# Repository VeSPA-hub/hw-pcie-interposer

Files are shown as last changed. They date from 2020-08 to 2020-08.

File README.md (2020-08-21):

# PCIe interposer

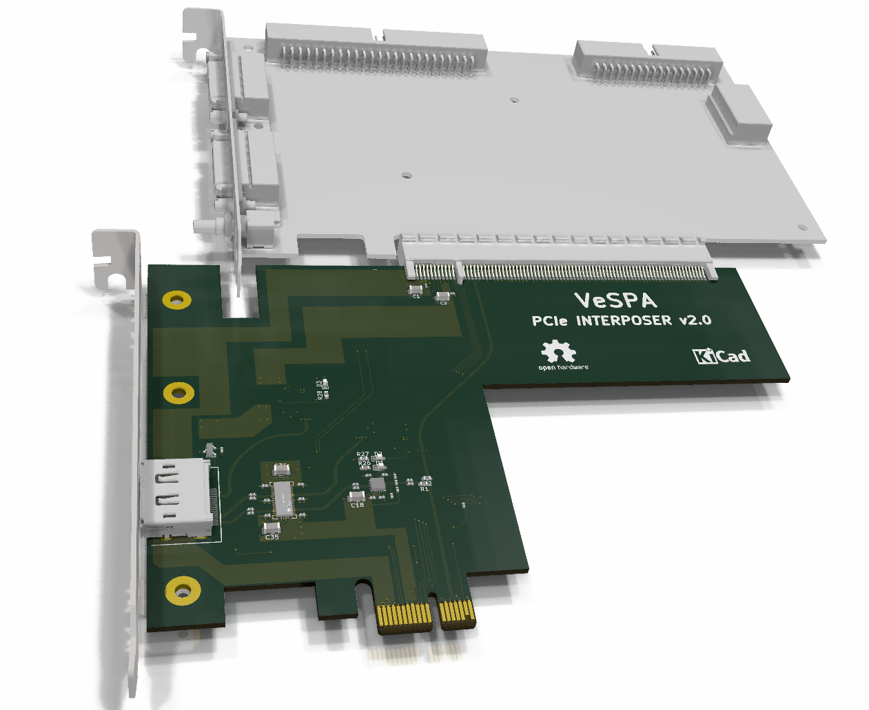
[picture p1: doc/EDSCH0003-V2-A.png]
interposer


Board design files of the VeSPA PCIe interposer

	Note: This design was performed in KiCad nightly , you will need a Nightly build to open and edit these source files.

# Status

This version has not been fully tested yet.

# What it is

This board can tap PCIe signals (RX, TX and clock) at Gen2 speed.
Signals go to a redriver before they are sent to the actual analyzer using a DisplayPort cable.

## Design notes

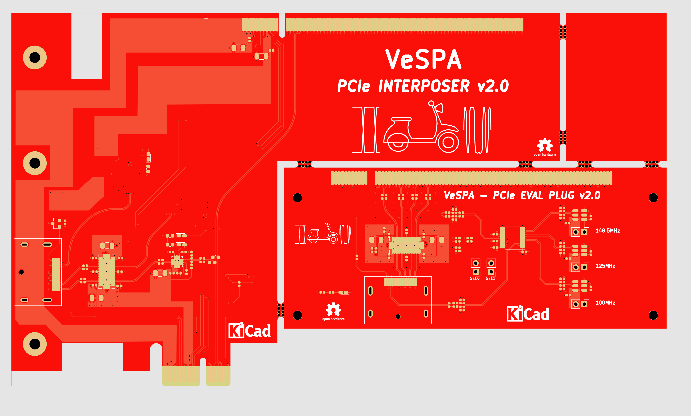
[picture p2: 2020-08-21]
gerber/board.png

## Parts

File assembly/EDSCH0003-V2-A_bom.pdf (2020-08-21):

EDSCH0003-V2-A

Page 1

Item | Qty | Reference | NC | Value | Footprint | Manufacturer | Part number | Mouser ordering code
1 | 7 | C1,C2,C18,C19,C20,C35,C36 | | 10uF | 1206 | TAIYO YUDEN | TMK316BJ106KL-T | 963-TMK316BJ106KL-T
2 | 6 | C6,C7,C8,C9,C10,C11 | | 10nF | 0402 | WURTH ELEKTRONIK | 885012205031 | 710-885012205031
3 | 23 | C3,C4,C5,C12,C13,C14,C15,C16,C17,C21,C22,C23,C24,C25,C26, C27,C28,C29,C30,C31,C32,C33,C34 | | 100nF | 0402 | WURTH ELEKTRONIK | 885012105016 | 710-885012105016
4 | 3 | D1,D2,D3 | | LED | 0603 | WURTH ELEKTRONIK | 150060VS55040 | 710-150060VS55040
5 | 3 | FB1,FB2,FB3 | | 600R | 0402 | TDK | MMZ1005S601HT000 | 810-MMZ1005S601HT000
6 | 1 | J1 | | PCIE EDGE x16 | | AMPHENOL FCI | 10146027-A40010LF | 649-10146027A40010LF
7 | 1 | J2 | | DISPLAYPORT | | MOLEX | 47272-0001 | 538-47272-0001
8 | 9 | R1,R2,R3,R4,R5,R6,R26,R27,R28 | | 680R | 0603 | VISHAY / DALE | CRCW0603680RJNEAC | 71-CRCW0603680RJNEAC
9 | 18 | R7,R8,R9,R10,R11,R12,R13,R14,R15,R20,R30,R31,R32,R33,R34 ,R35,R36,R37 | NC
10 | 4 | R16,R17,R18,R29 | | 33K | 0402 | VISHAY / DALE | CRCW040233K0FKEDC | 71-CRCW040233K0FKEDC
11 | 3 | R19,R21,R22 | | 0R | 0402 | VISHAY / DALE | CRCW04020000Z0EDC | 71-CRCW04020000Z0EDC
12 | 3 | R23,R24,R25 | | 100K | 0402 | VISHAY / DALE | CRCW0402100KFKEDC | 71-CRCW0402100KFKEDC
13 | 1 | U1 | | 11LC160T | SOT23 | MICROCHIP TECHNOLOGY | 11LC160T-I/TT | 579-11LC160T-I/TT
14 | 3 | U2,U3,U4 | | ONET1191P | QFN16 | TEXAS INSTRUMENTS | ONET1191PRGTT | 595-ONET1191PRGTT
15 | 1 | U5 | | SN65LVPE504 | PWQFN42 | TEXAS INSTRUMENTS | SN65LVPE504RUAR | 595-SN65LVPE504RUAR

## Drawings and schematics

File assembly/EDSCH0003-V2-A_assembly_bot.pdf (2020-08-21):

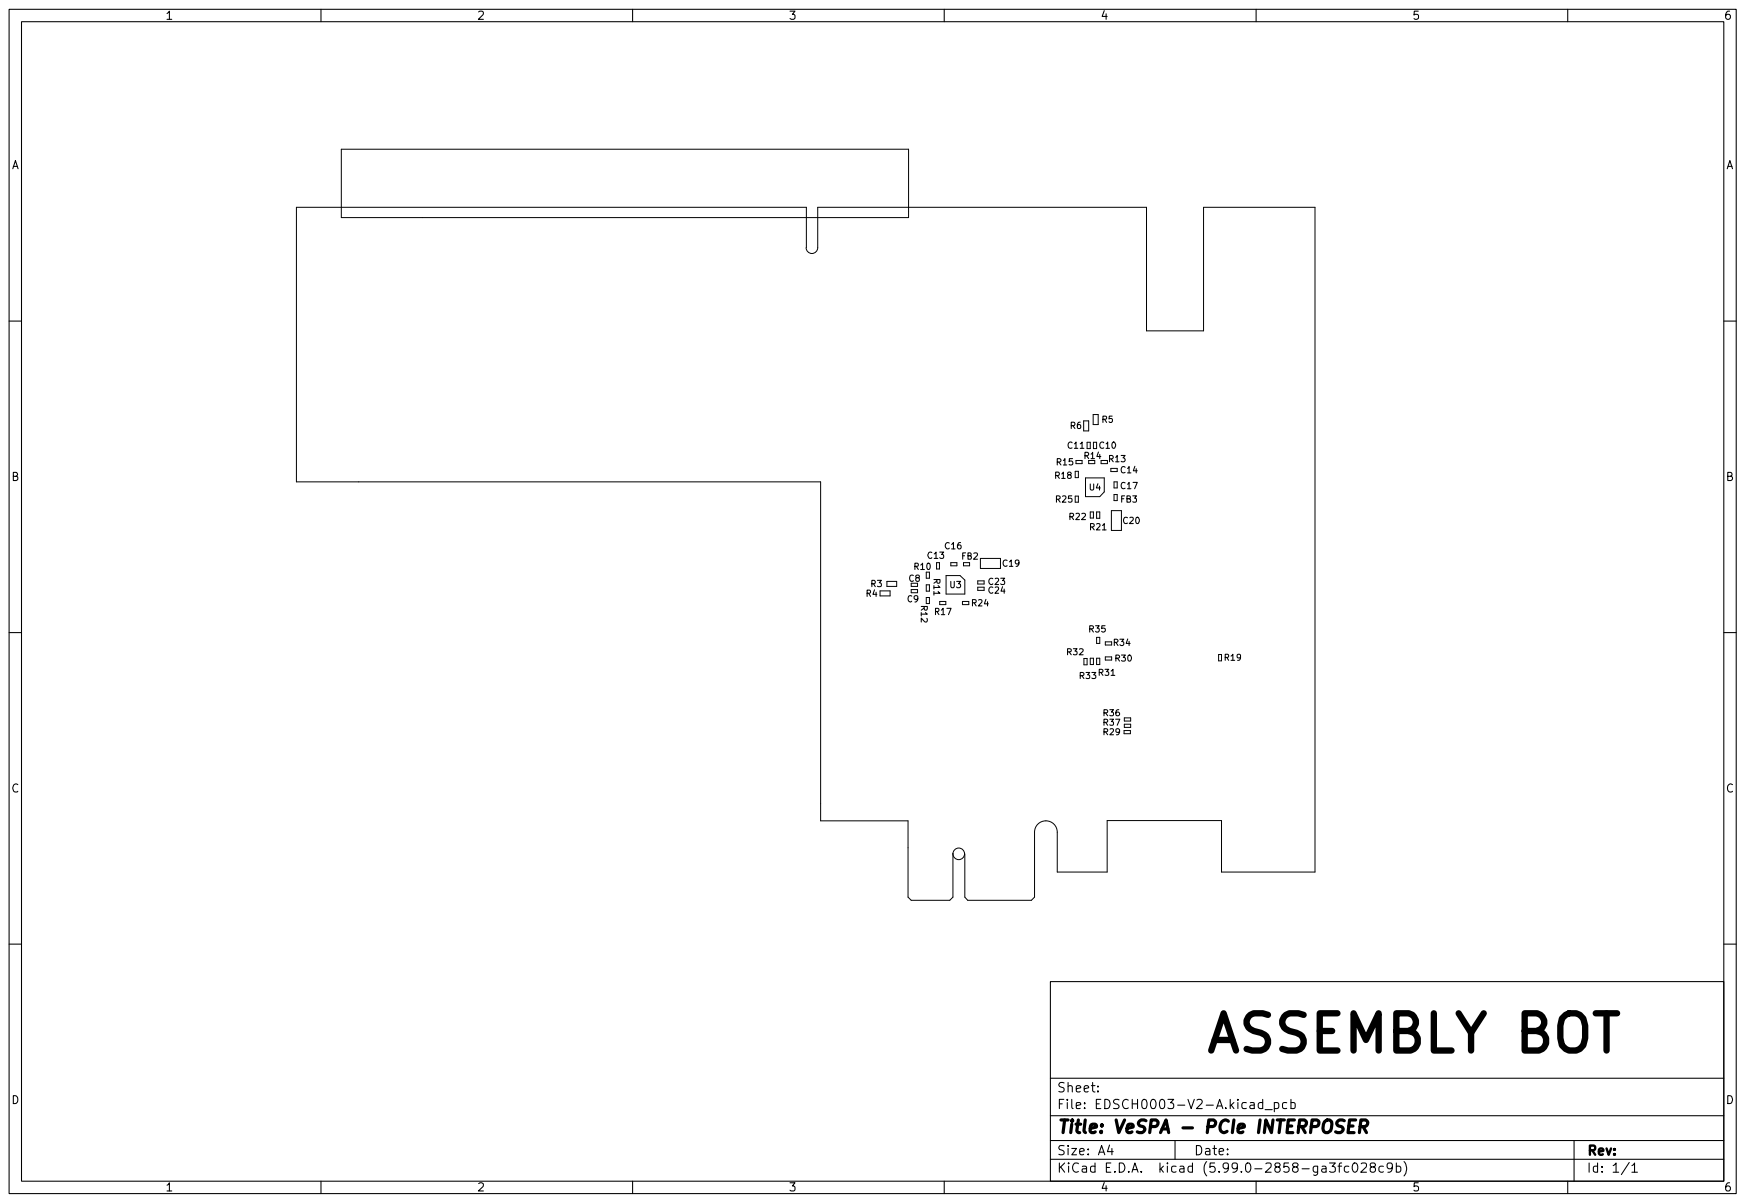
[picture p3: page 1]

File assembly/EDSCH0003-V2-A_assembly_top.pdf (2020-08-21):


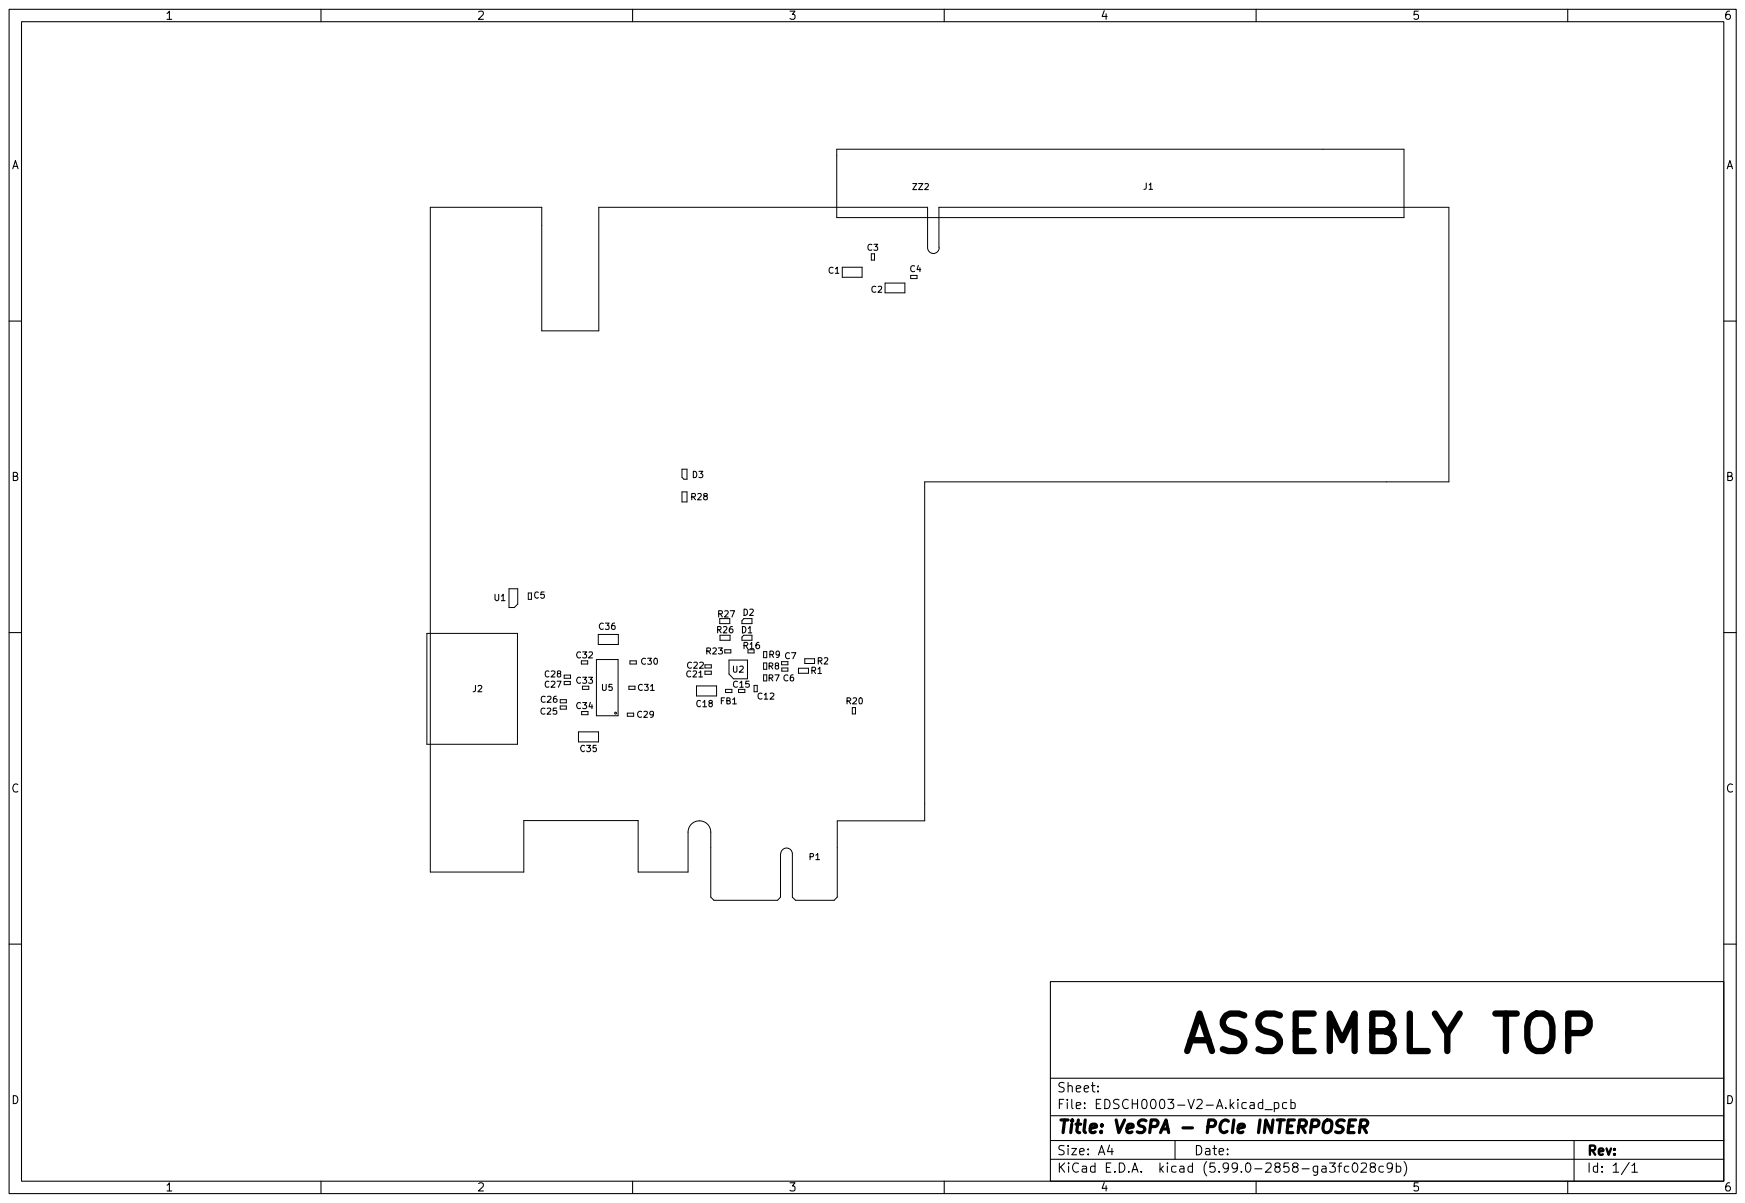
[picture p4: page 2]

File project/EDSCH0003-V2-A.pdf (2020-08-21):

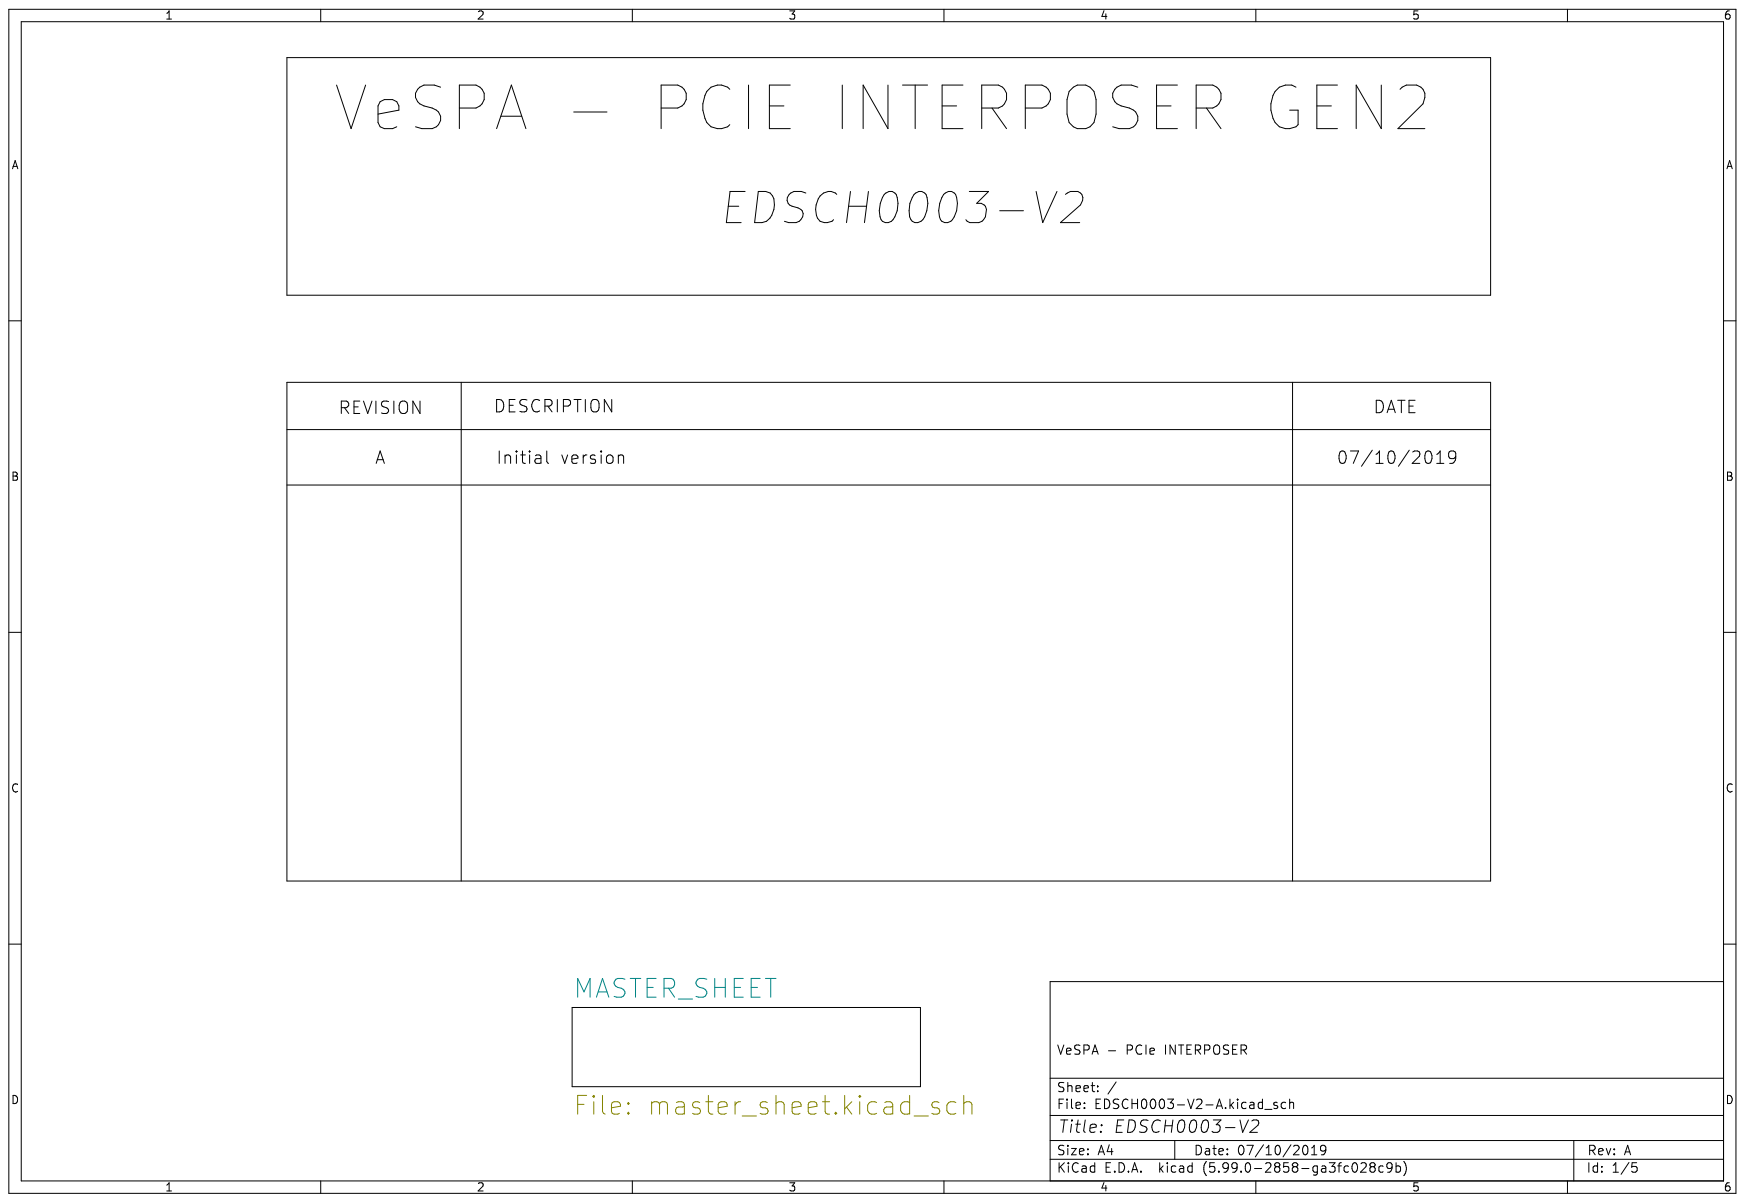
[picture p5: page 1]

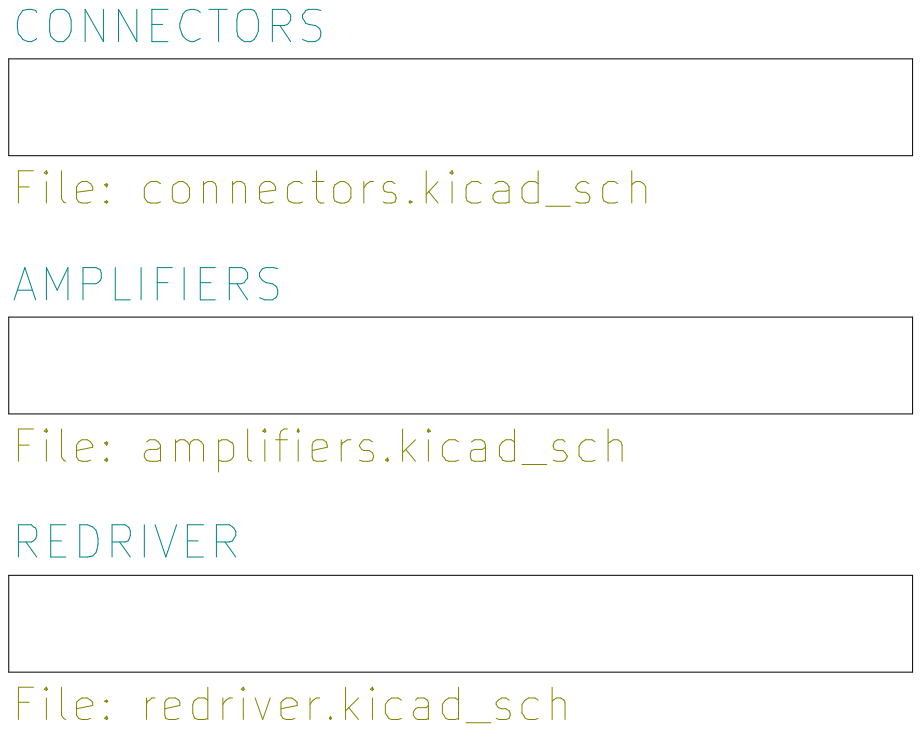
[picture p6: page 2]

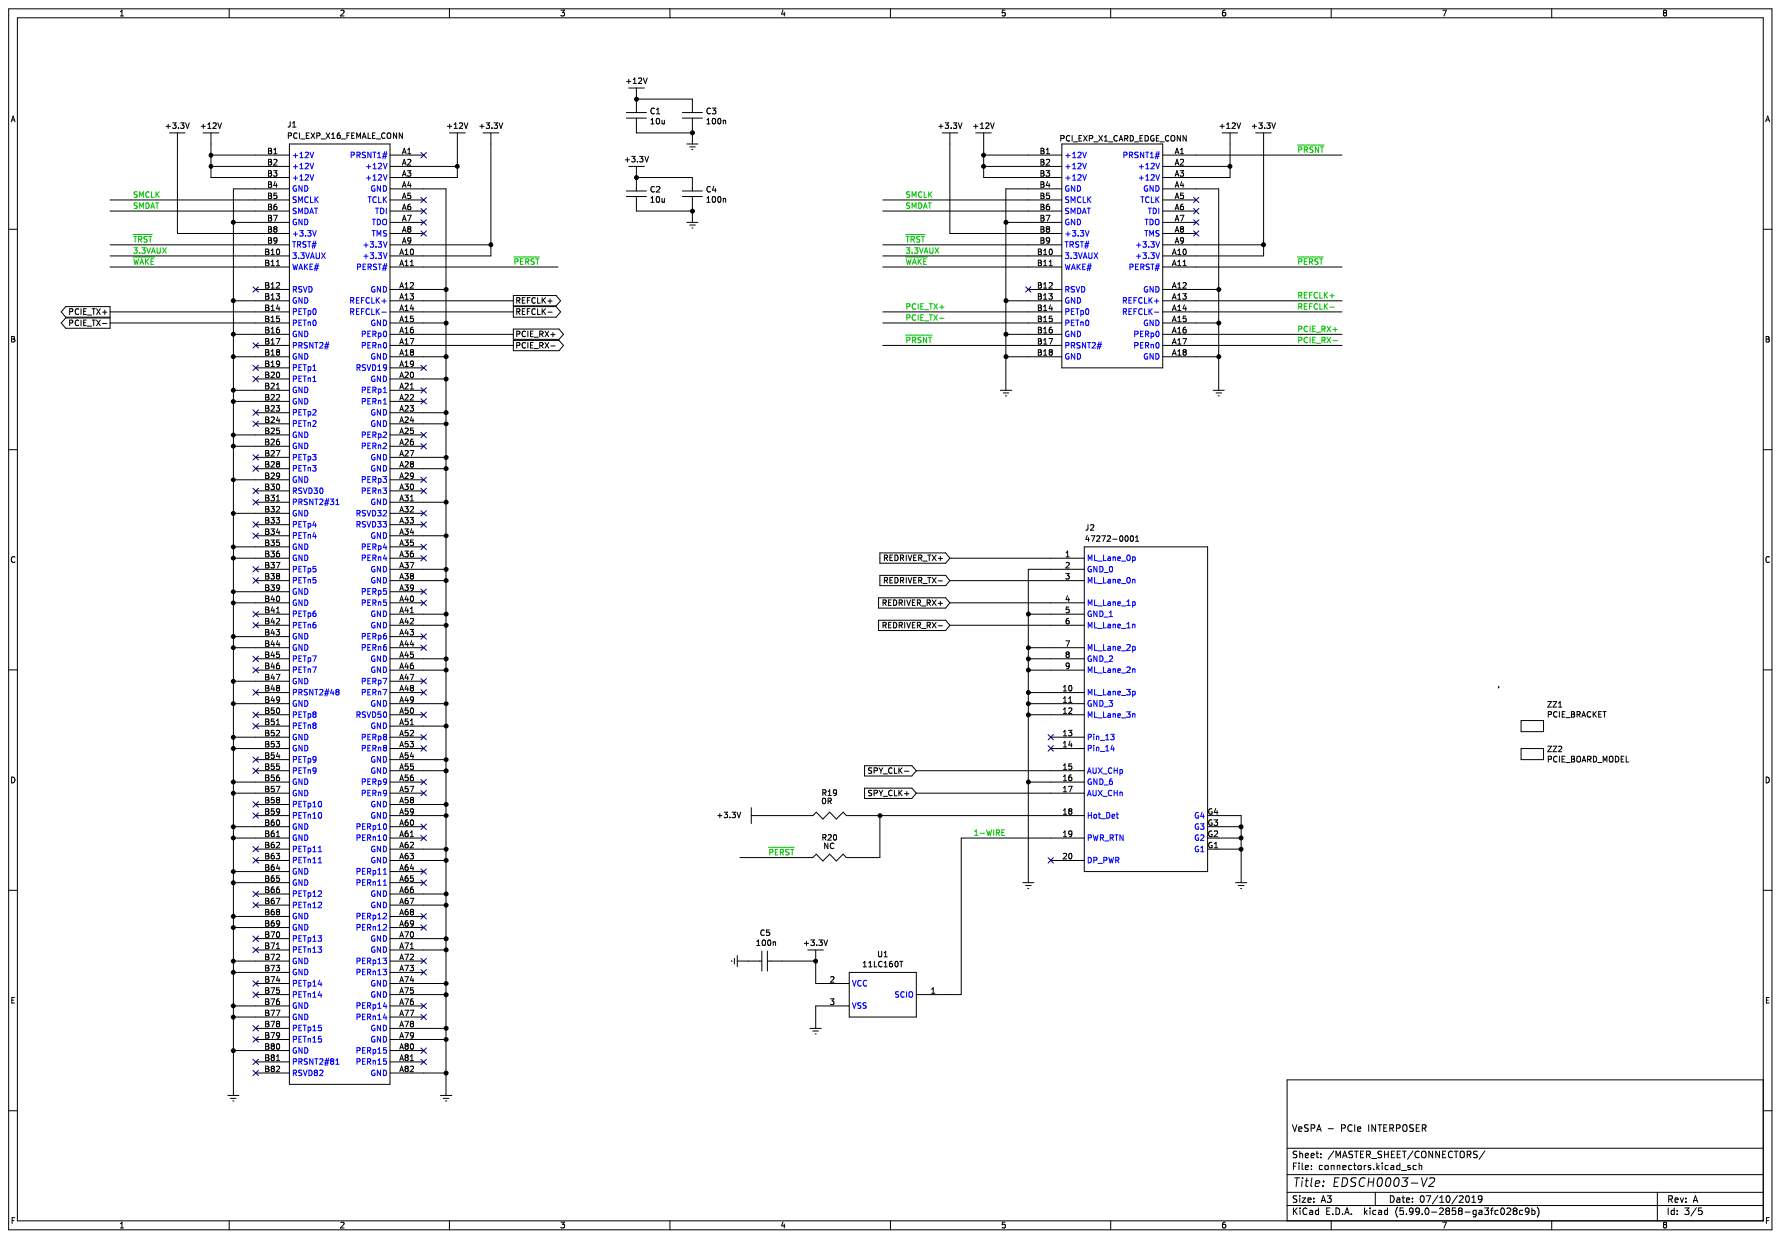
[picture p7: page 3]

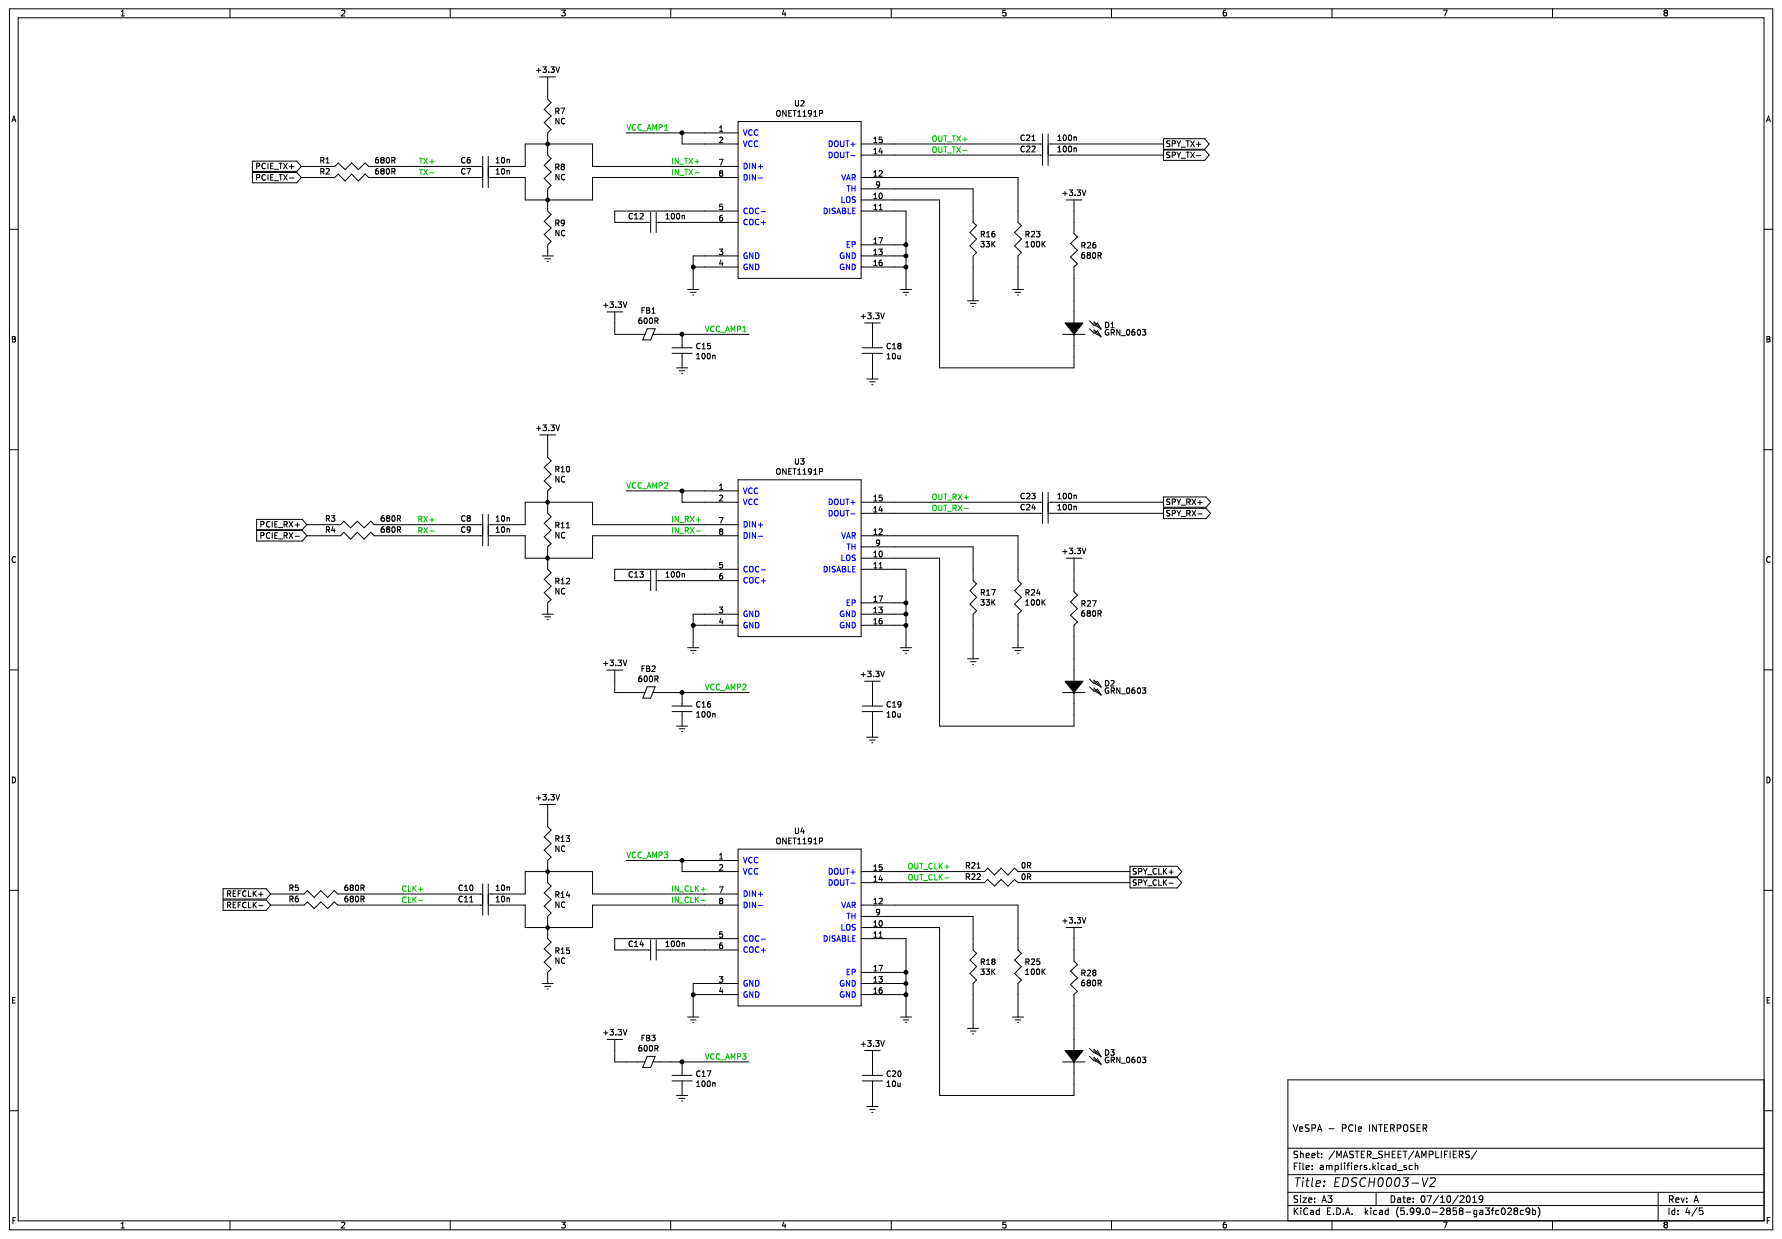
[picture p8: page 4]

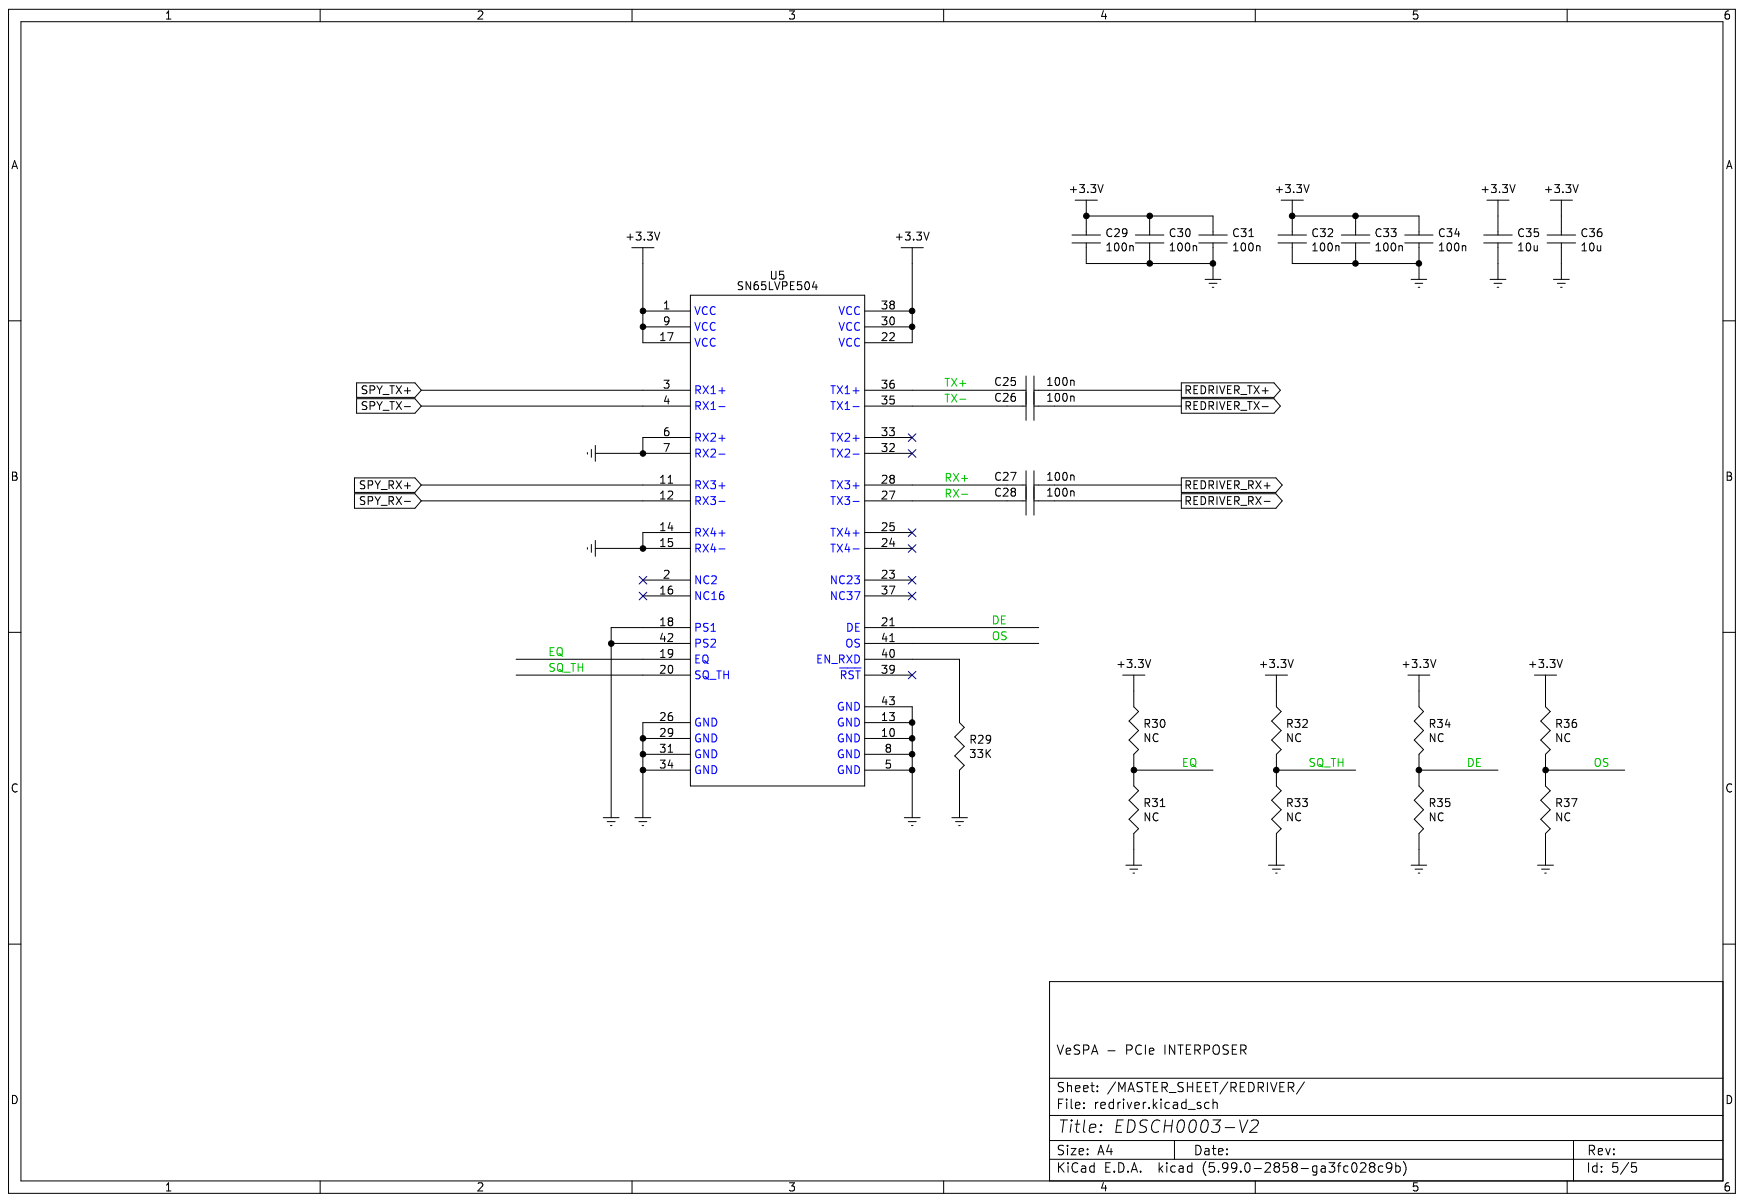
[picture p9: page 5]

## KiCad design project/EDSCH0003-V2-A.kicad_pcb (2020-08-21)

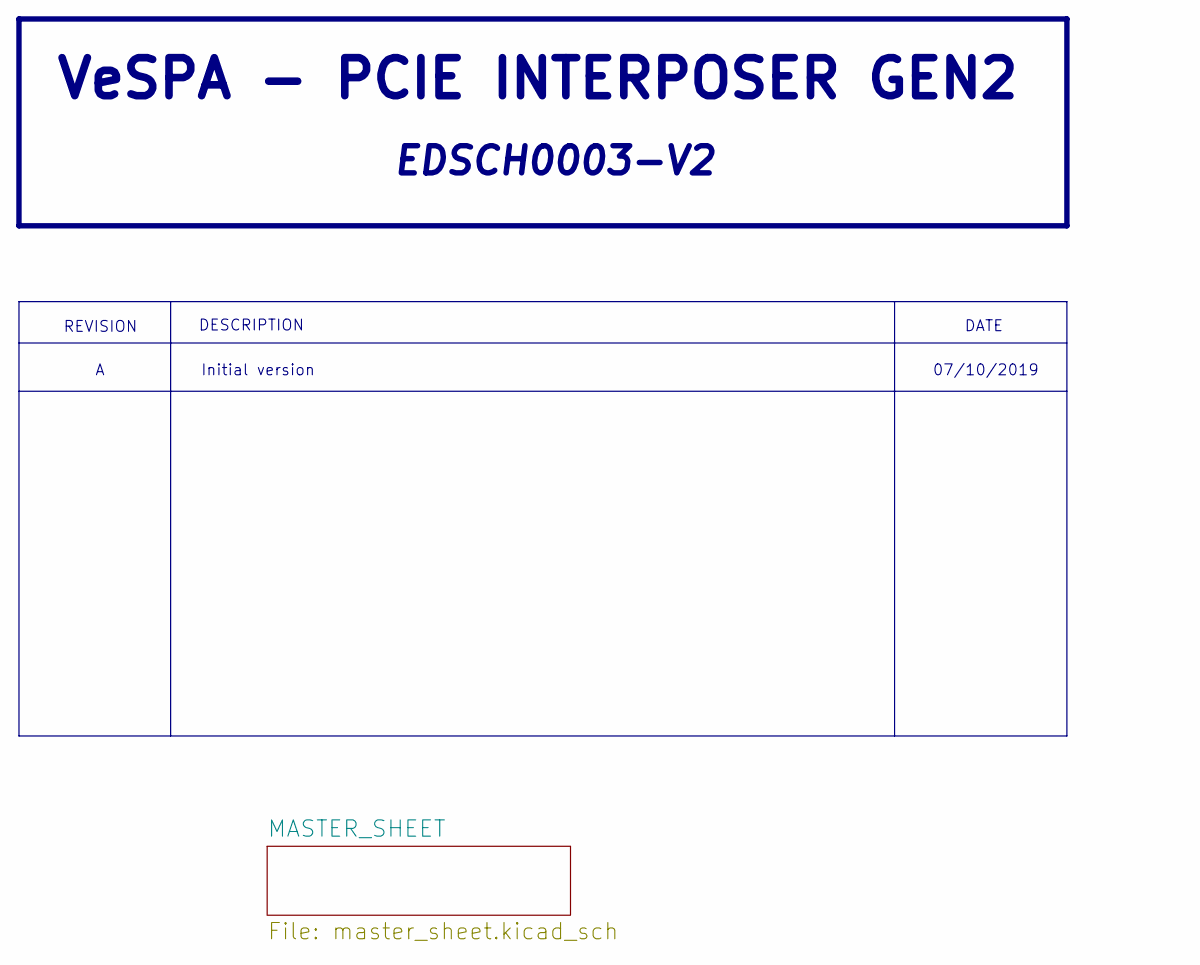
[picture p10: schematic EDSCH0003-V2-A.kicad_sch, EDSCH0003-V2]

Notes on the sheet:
VeSPA - PCIE INTERPOSER GEN2
REVISION
DESCRIPTION
Initial version
EDSCH0003-V2
DATE
07/10/2019

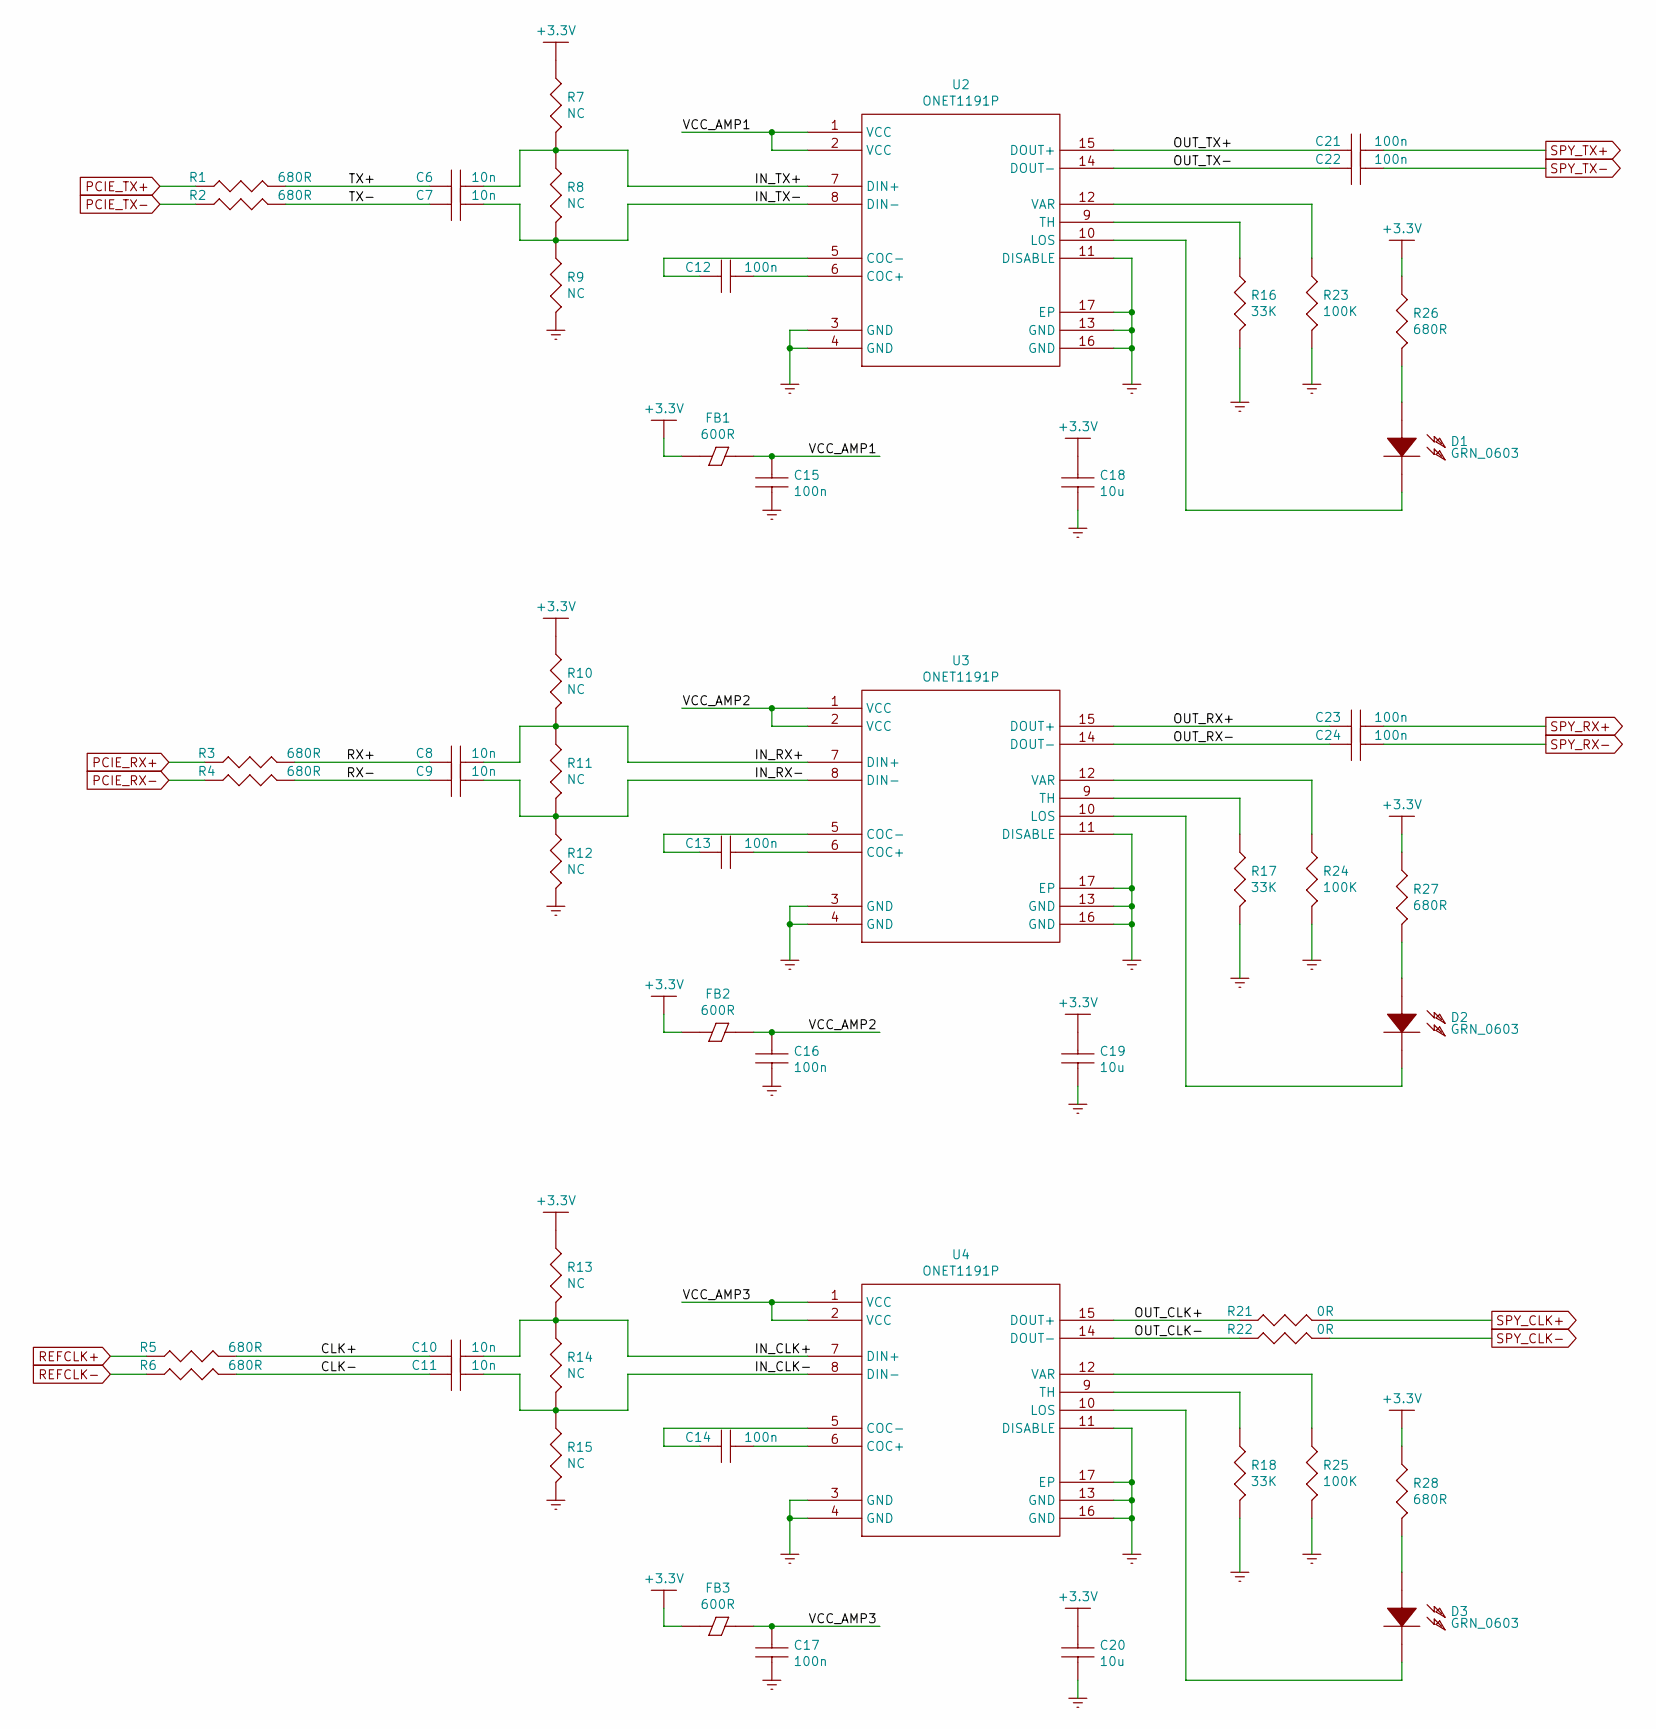
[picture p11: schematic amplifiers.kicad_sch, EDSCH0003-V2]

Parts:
C6, C7, C8, C9, C10, C11: C10N_0402; r_smt0402_ref
C12, C13, C14, C15, C16, C17, C21, C22, C23, C24: C100N_16V_0402; r_smt0402_ref
C18, C19, C20: C10U_50V_1206; c_smt1206_ref
D1, D2, D3: LED_GRN_0603; LED_0603_1608Metric_Castellated
FB1, FB2, FB3: FR_600R_0.2A_0402; r_smt0402_ref
R1, R2, R3, R4, R5, R6, R26, R27, R28: R680R_1%_0603; r_smt0603_ref
R7, R8, R9, R10, R11, R12, R13, R14, R15: R_NC_0402; r_smt0402_ref
R16, R17, R18: R33K_1%_0402; r_smt0402_ref
R21, R22: R0R_5%_0402; r_smt0402_ref
R23, R24, R25: R100K_1%_0402; r_smt0402_ref
U2, U3, U4: ONET1191P; QFN-16-1EP_3x3mm_P0.5mm_EP1.7x1.7mm

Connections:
+3.3V: C18.1, C19.1, C20.1, FB1.1, FB2.1, FB3.1, R7.1, R10.1, R13.1, R26.1, R27.1, R28.1; also elsewhere on the board
/MASTER_SHEET/AMPLIFIERS/CLK+: C10.1, R5.2
/MASTER_SHEET/AMPLIFIERS/CLK-: C11.1, R6.2
/MASTER_SHEET/AMPLIFIERS/IN_CLK+: C10.2, R13.2, R14.1, U4.7 (DIN+)
/MASTER_SHEET/AMPLIFIERS/IN_CLK-: C11.2, R14.2, R15.1, U4.8 (DIN-)
/MASTER_SHEET/AMPLIFIERS/IN_RX+: C8.2, R10.2, R11.1, U3.7 (DIN+)
/MASTER_SHEET/AMPLIFIERS/IN_RX-: C9.2, R11.2, R12.1, U3.8 (DIN-)
/MASTER_SHEET/AMPLIFIERS/IN_TX+: C6.2, R7.2, R8.1, U2.7 (DIN+)
/MASTER_SHEET/AMPLIFIERS/IN_TX-: C7.2, R8.2, R9.1, U2.8 (DIN-)
/MASTER_SHEET/AMPLIFIERS/OUT_CLK+: R21.1, U4.15 (DOUT+)
/MASTER_SHEET/AMPLIFIERS/OUT_CLK-: R22.1, U4.14 (DOUT-)
/MASTER_SHEET/AMPLIFIERS/OUT_RX+: C23.1, U3.15 (DOUT+)
/MASTER_SHEET/AMPLIFIERS/OUT_RX-: C24.1, U3.14 (DOUT-)
/MASTER_SHEET/AMPLIFIERS/OUT_TX+: C21.1, U2.15 (DOUT+)
/MASTER_SHEET/AMPLIFIERS/OUT_TX-: C22.1, U2.14 (DOUT-)
/MASTER_SHEET/AMPLIFIERS/RX+: C8.1, R3.2
/MASTER_SHEET/AMPLIFIERS/RX-: C9.1, R4.2
/MASTER_SHEET/AMPLIFIERS/TX+: C6.1, R1.2
/MASTER_SHEET/AMPLIFIERS/TX-: C7.1, R2.2
/MASTER_SHEET/AMPLIFIERS/VCC_AMP1: C15.1, FB1.2, U2.1 (VCC), U2.2 (VCC)
/MASTER_SHEET/AMPLIFIERS/VCC_AMP2: C16.1, FB2.2, U3.1 (VCC), U3.2 (VCC)
/MASTER_SHEET/AMPLIFIERS/VCC_AMP3: C17.1, FB3.2, U4.1 (VCC), U4.2 (VCC)
GND: C15.2, C16.2, C17.2, C18.2, C19.2, C20.2, R9.2, R12.2, R15.2, R16.2, R17.2, R18.2, R23.2, R24.2, R25.2, U2.3 (GND), U2.4 (GND), U2.11 (DISABLE), U2.13 (GND), U2.16 (GND), U2.17 (EP), U3.3 (GND), U3.4 (GND), U3.11 (DISABLE), U3.13 (GND), U3.16 (GND), U3.17 (EP), U4.3 (GND), U4.4 (GND), U4.11 (DISABLE), U4.13 (GND), U4.16 (GND), U4.17 (EP); also elsewhere on the board
unnamed: C12.1, U2.5 (COC-)
unnamed: C12.2, U2.6 (COC+)
unnamed: C13.1, U3.5 (COC-)
unnamed: C13.2, U3.6 (COC+)
unnamed: C14.1, U4.5 (COC-)
unnamed: C14.2, U4.6 (COC+)
unnamed: D1.1 (A), R26.2
unnamed: D1.2 (K), U2.10 (LOS)
unnamed: D2.1 (A), R27.2
unnamed: D2.2 (K), U3.10 (LOS)
unnamed: D3.1 (A), R28.2
unnamed: D3.2 (K), U4.10 (LOS)
unnamed: R16.1, U2.9 (TH)
unnamed: R17.1, U3.9 (TH)
unnamed: R18.1, U4.9 (TH)
unnamed: R23.1, U2.12 (VAR)
unnamed: R24.1, U3.12 (VAR)
unnamed: R25.1, U4.12 (VAR)
PCIE_RX+: R3.1; also elsewhere on the board
PCIE_RX-: R4.1; also elsewhere on the board
PCIE_TX+: R1.1; also elsewhere on the board
PCIE_TX-: R2.1; also elsewhere on the board
REFCLK+: R5.1; also elsewhere on the board
REFCLK-: R6.1; also elsewhere on the board
SPY_CLK+: R21.2; also elsewhere on the board
SPY_CLK-: R22.2; also elsewhere on the board
SPY_RX+: C23.2; also elsewhere on the board
SPY_RX-: C24.2; also elsewhere on the board
SPY_TX+: C21.2; also elsewhere on the board
SPY_TX-: C22.2; also elsewhere on the board

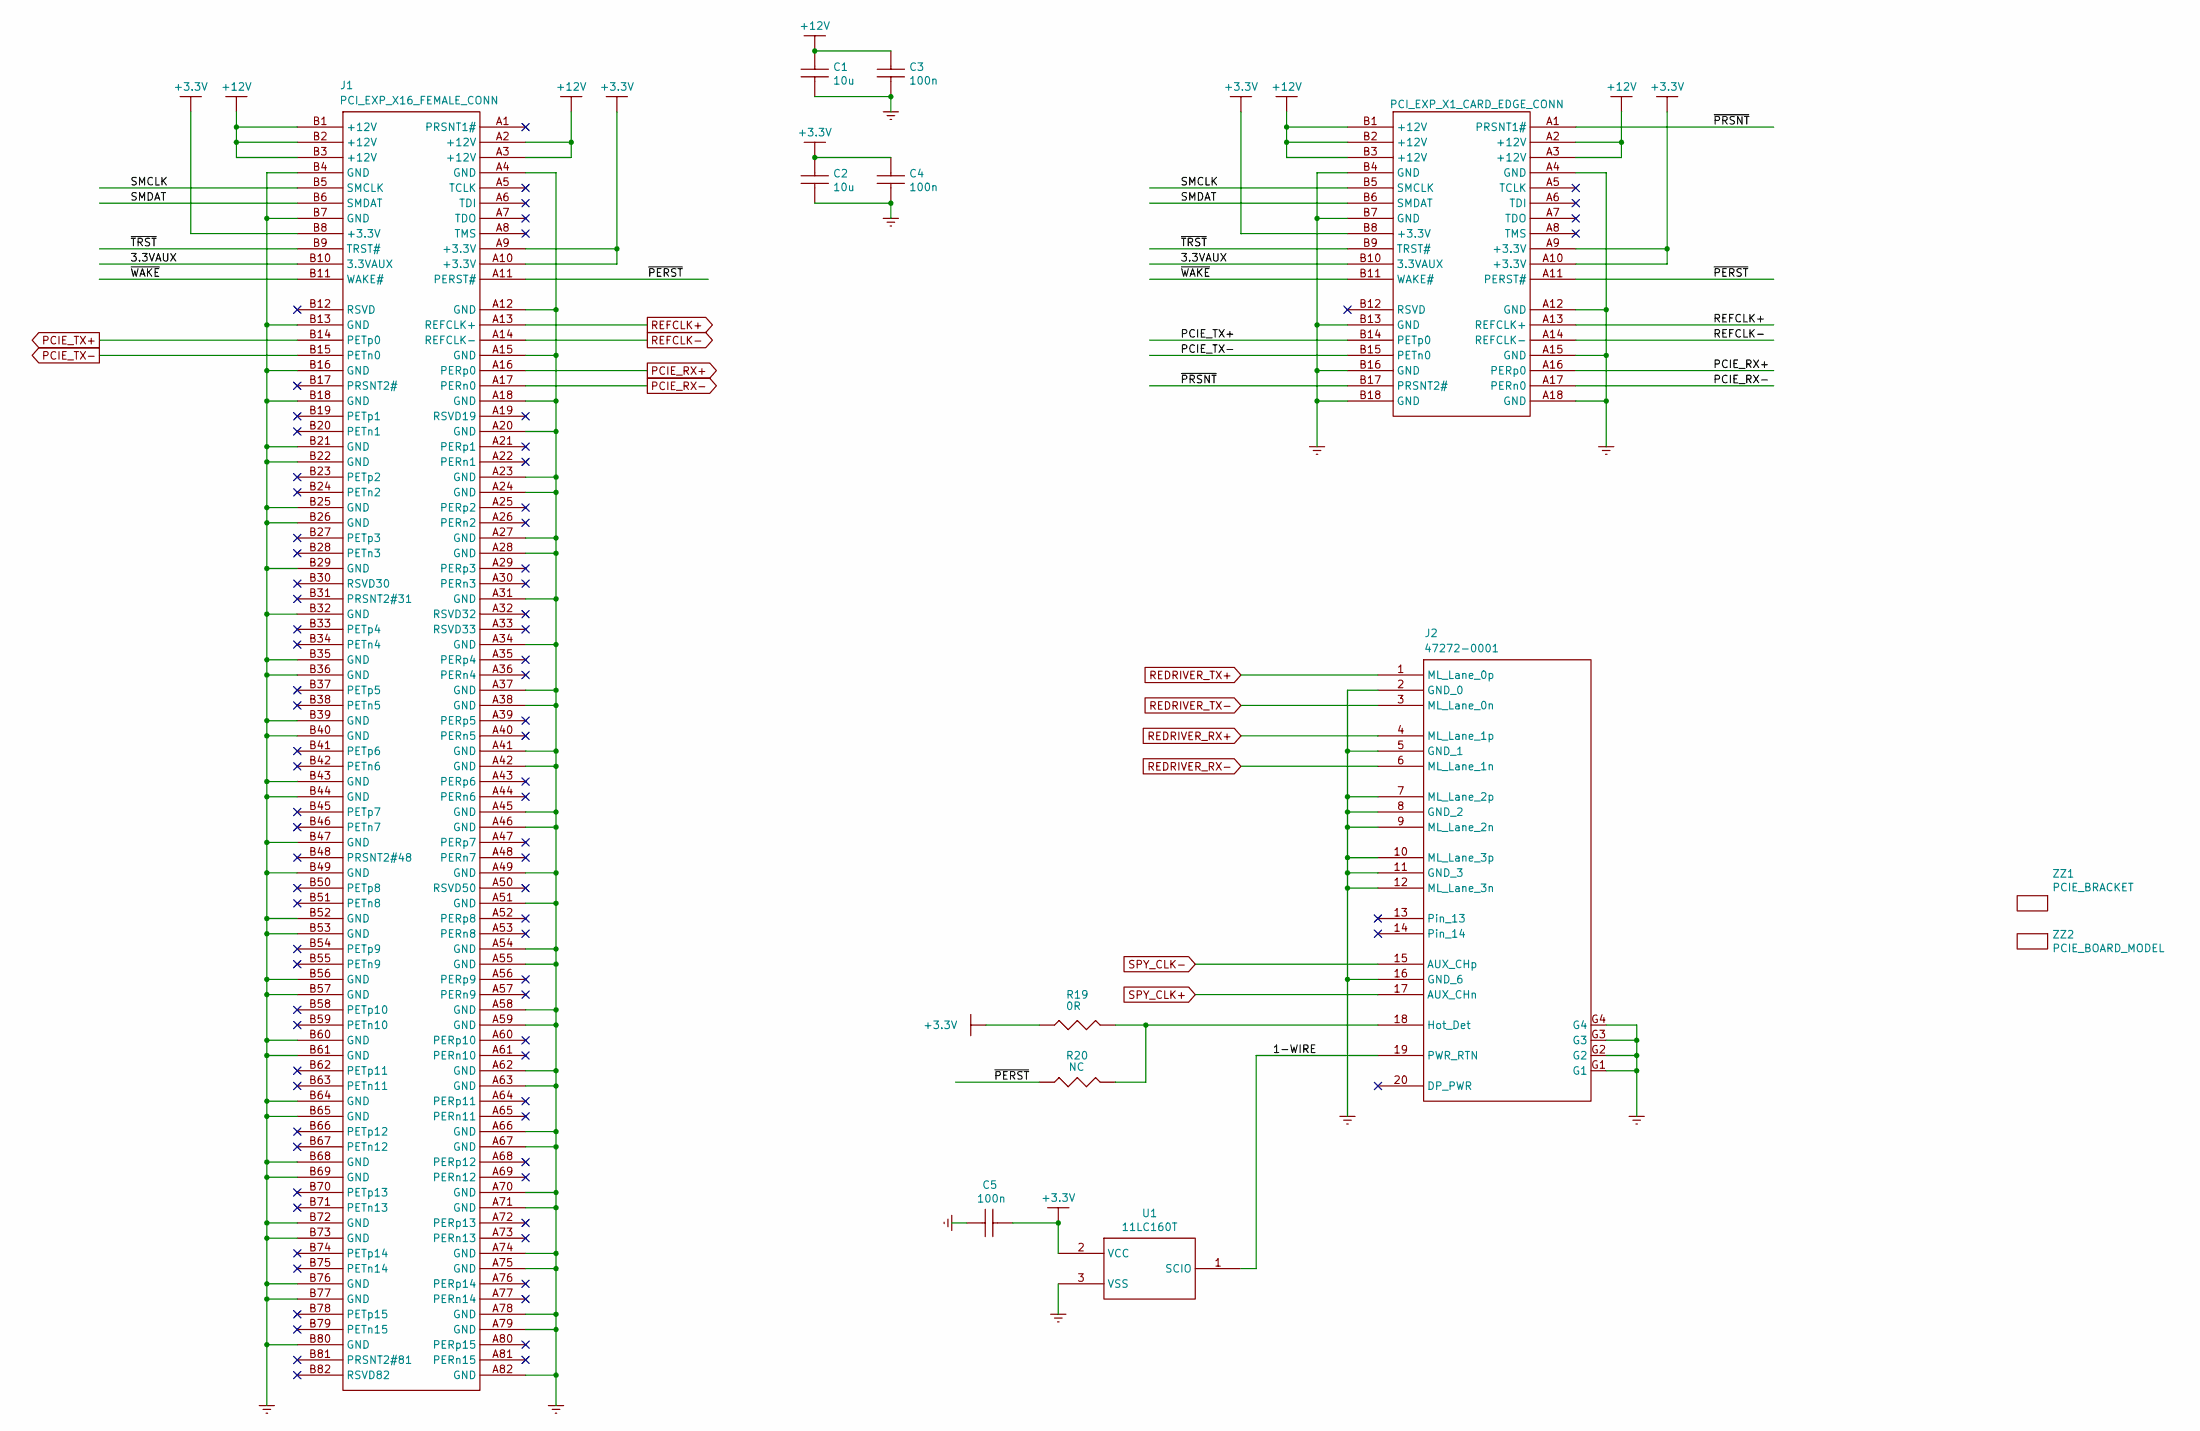
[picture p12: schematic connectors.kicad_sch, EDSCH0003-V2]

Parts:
C1, C2: C10U_50V_1206; c_smt1206_ref
C3, C4, C5: C100N_16V_0402; r_smt0402_ref
J1: PCIEXP_X16_EDGE_MOUNT_CONN; samtec_pcie_ems2
J2: DISPLAY_PORT; molex_display_port
P1: PCIEXP_X1_CARD_EDGE; BUS_PCIexpress_x1
R19: R0R_5%_0402; r_smt0402_ref
R20: R_NC_0402; r_smt0402_ref
U1: EEPROM_1WIRE_2Kx8_11LC160T; SOT-23
ZZ1: PCIE_BRACKET; pcie_bracket
ZZ2: PCIE_BOARD_MODEL; BUS_PCIexpress

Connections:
+3.3V: C2.1, C4.1, C5.2, J1.A9 (+3.3V), J1.A10 (+3.3V), J1.B8 (+3.3V), P1.A9 (+3.3V), P1.A10 (+3.3V), P1.B8 (+3.3V), R19.1, U1.2 (VCC); also elsewhere on the board
+12V: C1.1, C3.1, J1.A2 (+12V), J1.A3 (+12V), J1.B1 (+12V), J1.B2 (+12V), J1.B3 (+12V), P1.A2 (+12V), P1.A3 (+12V), P1.B1 (+12V), P1.B2 (+12V), P1.B3 (+12V)
/MASTER_SHEET/CONNECTORS/1-WIRE: J2.19 (PWR_RTN), U1.1 (SCIO)
/MASTER_SHEET/CONNECTORS/3.3VAUX: J1.B10 (3.3VAUX), P1.B10 (3.3VAUX)
/MASTER_SHEET/CONNECTORS/SMCLK: J1.B5 (SMCLK), P1.B5 (SMCLK)
/MASTER_SHEET/CONNECTORS/SMDAT: J1.B6 (SMDAT), P1.B6 (SMDAT)
/MASTER_SHEET/CONNECTORS/~PERST: J1.A11 (PERST#), P1.A11 (PERST#), R20.1
/MASTER_SHEET/CONNECTORS/~PRSNT: P1.A1 (PRSNT1#), P1.B17 (PRSNT2#)
/MASTER_SHEET/CONNECTORS/~TRST: J1.B9 (TRST#), P1.B9 (TRST#)
/MASTER_SHEET/CONNECTORS/~WAKE: J1.B11 (WAKE#), P1.B11 (WAKE#)
GND: C1.2, C2.2, C3.2, C4.2, C5.1, J1.A4 (GND), J1.A12 (GND), J1.A15 (GND), J1.A18 (GND), J1.A20 (GND), J1.A23 (GND), J1.A24 (GND), J1.A27 (GND), J1.A28 (GND), J1.A31 (GND), J1.A34 (GND), J1.A37 (GND), J1.A38 (GND), J1.A41 (GND), J1.A42 (GND), J1.A45 (GND), J1.A46 (GND), J1.A49 (GND), J1.A51 (GND), J1.A54 (GND), J1.A55 (GND), J1.A58 (GND), J1.A59 (GND), J1.A62 (GND), J1.A63 (GND), J1.A66 (GND), J1.A67 (GND), J1.A70 (GND), J1.A71 (GND), J1.A74 (GND), J1.A75 (GND), J1.A78 (GND), J1.A79 (GND), J1.A82 (GND), J1.B4 (GND), J1.B7 (GND), J1.B13 (GND), J1.B16 (GND), J1.B18 (GND), J1.B21 (GND), J1.B22 (GND), J1.B25 (GND), J1.B26 (GND), J1.B29 (GND), J1.B32 (GND), J1.B35 (GND), J1.B36 (GND), J1.B39 (GND), J1.B40 (GND), J1.B43 (GND), J1.B44 (GND), J1.B47 (GND), J1.B49 (GND), J1.B52 (GND), J1.B53 (GND), J1.B56 (GND), J1.B57 (GND), J1.B60 (GND), J1.B61 (GND), J1.B64 (GND), J1.B65 (GND), J1.B68 (GND), J1.B69 (GND), J1.B72 (GND), J1.B73 (GND), J1.B76 (GND), J1.B77 (GND), J1.B80 (GND), J2.2 (GND_0), J2.5 (GND_1), J2.7 (ML_Lane_2p), J2.8 (GND_2), J2.9 (ML_Lane_2n), J2.10 (ML_Lane_3p), J2.11 (GND_3), J2.12 (ML_Lane_3n), J2.16 (GND_6), J2.G1, J2.G2, J2.G3, J2.G4, P1.A4 (GND), P1.A12 (GND), P1.A15 (GND), P1.A18 (GND), P1.B4 (GND), P1.B7 (GND), P1.B13 (GND), P1.B16 (GND), P1.B18 (GND), U1.3 (VSS); also elsewhere on the board
unnamed: J2.18 (Hot_Det), R19.2, R20.2
PCIE_RX+: J1.A16 (PERp0), P1.A16 (PERp0); also elsewhere on the board
PCIE_RX-: J1.A17 (PERn0), P1.A17 (PERn0); also elsewhere on the board
PCIE_TX+: J1.B14 (PETp0), P1.B14 (PETp0); also elsewhere on the board
PCIE_TX-: J1.B15 (PETn0), P1.B15 (PETn0); also elsewhere on the board
REDRIVER_RX+: J2.4 (ML_Lane_1p); also elsewhere on the board
REDRIVER_RX-: J2.6 (ML_Lane_1n); also elsewhere on the board
REDRIVER_TX+: J2.1 (ML_Lane_0p); also elsewhere on the board
REDRIVER_TX-: J2.3 (ML_Lane_0n); also elsewhere on the board
REFCLK+: J1.A13 (REFCLK+), P1.A13 (REFCLK+); also elsewhere on the board
REFCLK-: J1.A14 (REFCLK-), P1.A14 (REFCLK-); also elsewhere on the board
SPY_CLK+: J2.17 (AUX_CHn); also elsewhere on the board
SPY_CLK-: J2.15 (AUX_CHp); also elsewhere on the board

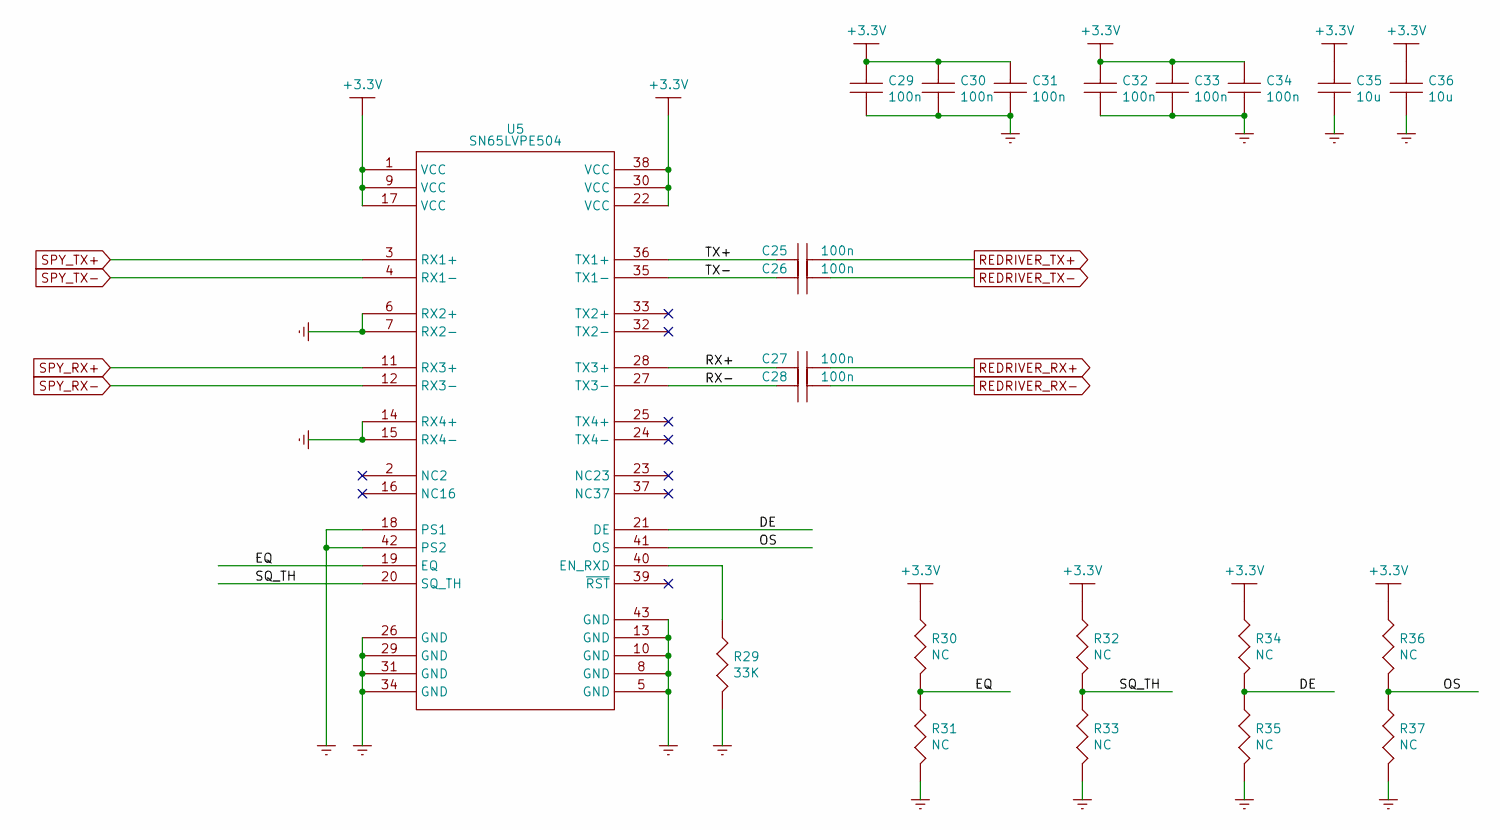
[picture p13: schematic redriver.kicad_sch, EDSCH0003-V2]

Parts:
C25, C26, C27, C28, C29, C30, C31, C32, C33, C34: C100N_16V_0402; r_smt0402_ref
C35, C36: C10U_50V_1206; c_smt1206_ref
R29: R33K_1%_0402; r_smt0402_ref
R30, R31, R32, R33, R34, R35, R36, R37: R_NC_0402; r_smt0402_ref
U5: PCIe_HALF_x4_Gen2_SN65LVPE504; pwqfn-n42

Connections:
+3.3V: C29.1, C30.1, C31.1, C32.1, C33.1, C34.1, C35.1, C36.1, R30.1, R32.1, R34.1, R36.1, U5.1 (VCC), U5.9 (VCC), U5.17 (VCC), U5.22 (VCC), U5.30 (VCC), U5.38 (VCC); also elsewhere on the board
/MASTER_SHEET/REDRIVER/DE: R34.2, R35.1, U5.21 (DE)
/MASTER_SHEET/REDRIVER/EQ: R30.2, R31.1, U5.19 (EQ)
/MASTER_SHEET/REDRIVER/OS: R36.2, R37.1, U5.41 (OS)
/MASTER_SHEET/REDRIVER/RX+: C27.1, U5.28 (TX3+)
/MASTER_SHEET/REDRIVER/RX-: C28.1, U5.27 (TX3-)
/MASTER_SHEET/REDRIVER/SQ_TH: R32.2, R33.1, U5.20 (SQ_TH)
/MASTER_SHEET/REDRIVER/TX+: C25.1, U5.36 (TX1+)
/MASTER_SHEET/REDRIVER/TX-: C26.1, U5.35 (TX1-)
GND: C29.2, C30.2, C31.2, C32.2, C33.2, C34.2, C35.2, C36.2, R29.2, R31.2, R33.2, R35.2, R37.2, U5.5 (GND), U5.6 (RX2+), U5.7 (RX2-), U5.8 (GND), U5.10 (GND), U5.13 (GND), U5.14 (RX4+), U5.15 (RX4-), U5.18 (PS1), U5.26 (GND), U5.29 (GND), U5.31 (GND), U5.34 (GND), U5.42 (PS2), U5.43 (GND); also elsewhere on the board
unnamed: R29.1, U5.40 (EN_RXD)
REDRIVER_RX+: C27.2; also elsewhere on the board
REDRIVER_RX-: C28.2; also elsewhere on the board
REDRIVER_TX+: C25.2; also elsewhere on the board
REDRIVER_TX-: C26.2; also elsewhere on the board
SPY_RX+: U5.11 (RX3+); also elsewhere on the board
SPY_RX-: U5.12 (RX3-); also elsewhere on the board
SPY_TX+: U5.3 (RX1+); also elsewhere on the board
SPY_TX-: U5.4 (RX1-); also elsewhere on the board

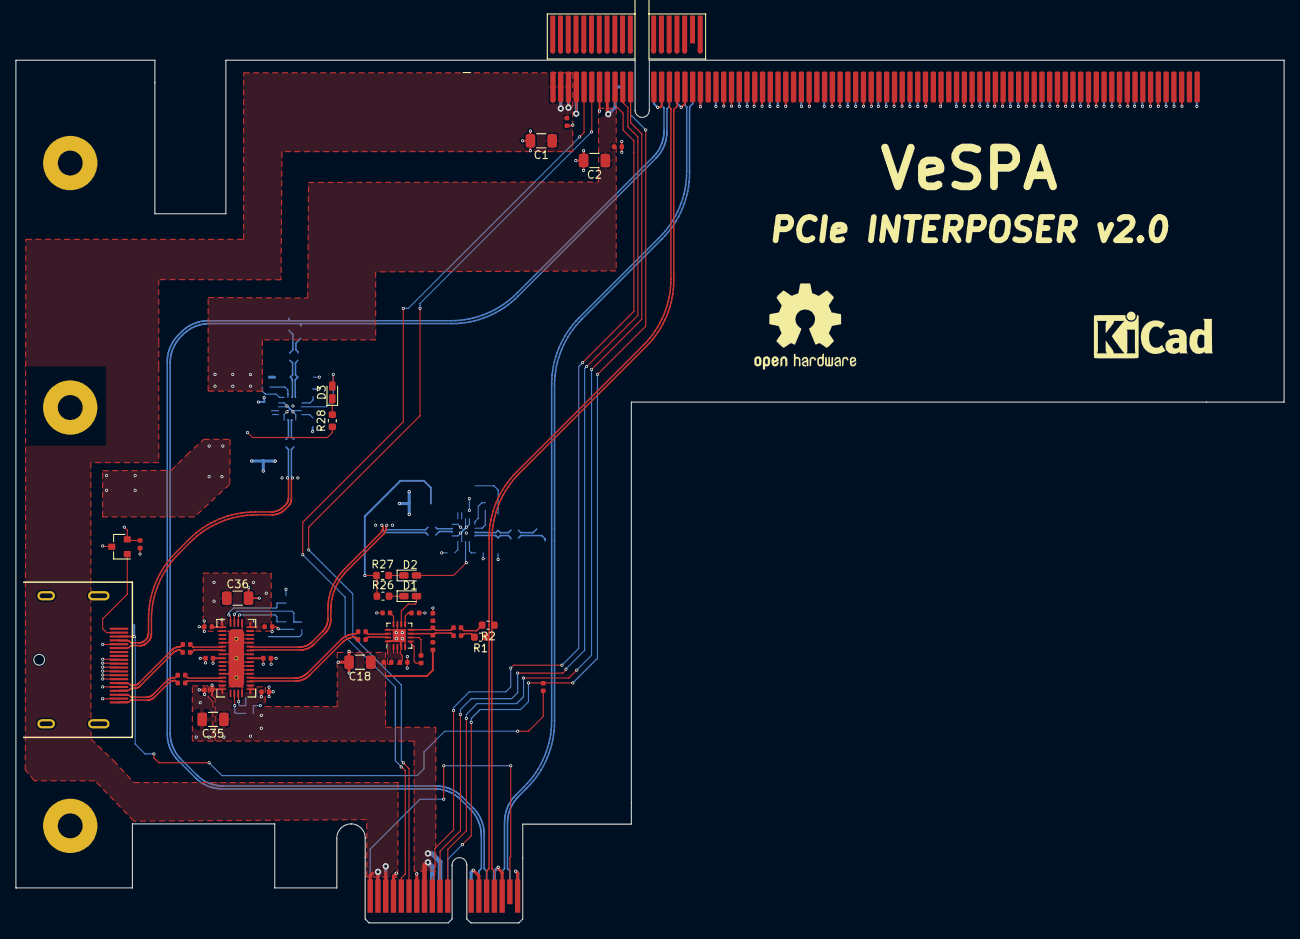
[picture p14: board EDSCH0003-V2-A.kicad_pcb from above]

Board: 4 copper layers, 163.4 x 111.2 mm, 89 parts (0 on the bottom side), 76 nets.

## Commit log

2020-07-30 Initial release
    [EDSCH0003-V2-A.kicad_pcb, EDSCH0003-V2-A.kicad_sch, EDSCH0003-V2-A.ods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]
2020-08-21 Clean-up files
    [EDSCH0003-V2-A.kicad_pcb, EDSCH0003-V2-A.kicad_sch, EDSCH0003-V2-A.ods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]
2020-08-21 Add gerber files
    [fab_v2-B_Mask.gbr, fab_v2-B_Paste.gbr, fab_v2-B_SilkS.gbr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]
